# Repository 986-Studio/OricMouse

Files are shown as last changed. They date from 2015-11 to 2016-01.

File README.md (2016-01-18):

# OricMouse
OricMouse, an Expansion card to add Mouse to your Orices! (1, Atmos and Telestrat)

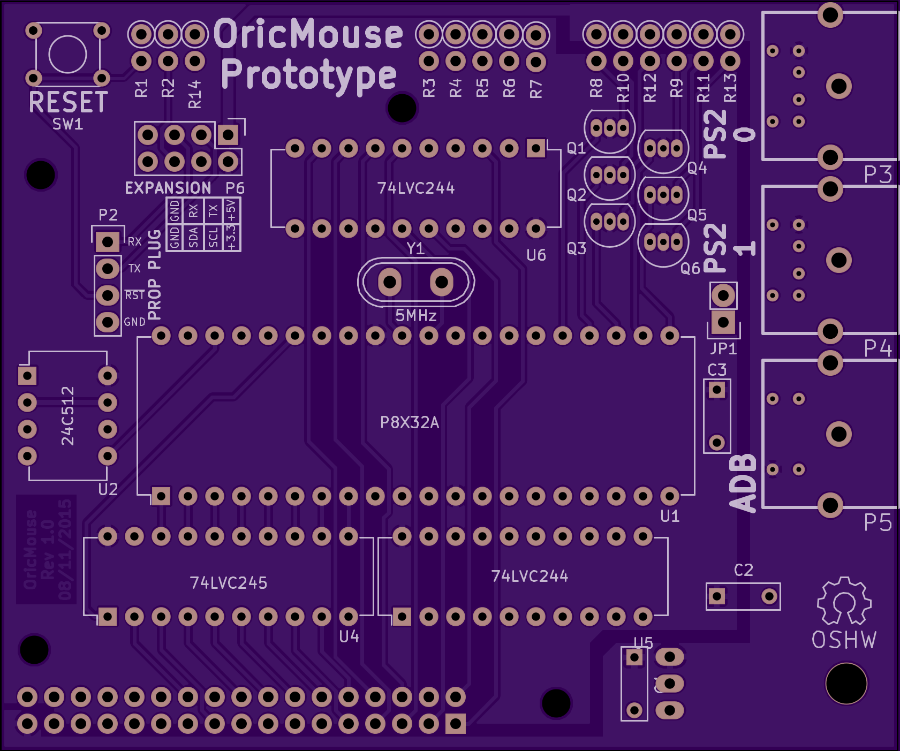
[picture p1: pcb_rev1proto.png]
PCB Design


You will find both the hardware and firmware of this project in this repository. 

OricMouse is an Open Source Hardware project.

Ready to order gerber can be found on OSHPark: https://oshpark.com/shared_projects/KOAZTB95

The correct license still need to be choosen, but please concidere it currently as something similar to the 4 clause BSD, share and use as wanted, but always tell from what your project is based, and who is the original author.
__Also if you make your own derived project, do not use the same name or a derived name.__ That mean that you can use the Oric name as I don't own this name, but don't use "OricMouse".

3D Rendering of the PCB:
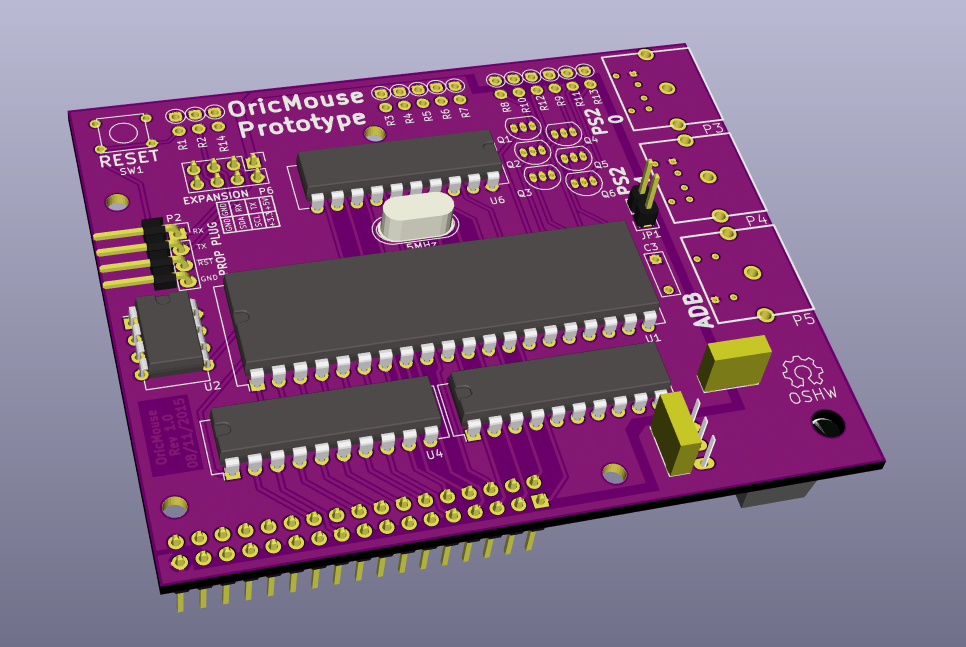
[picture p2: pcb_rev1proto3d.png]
3D Render of current PCB Design


Older revision of the PCB:
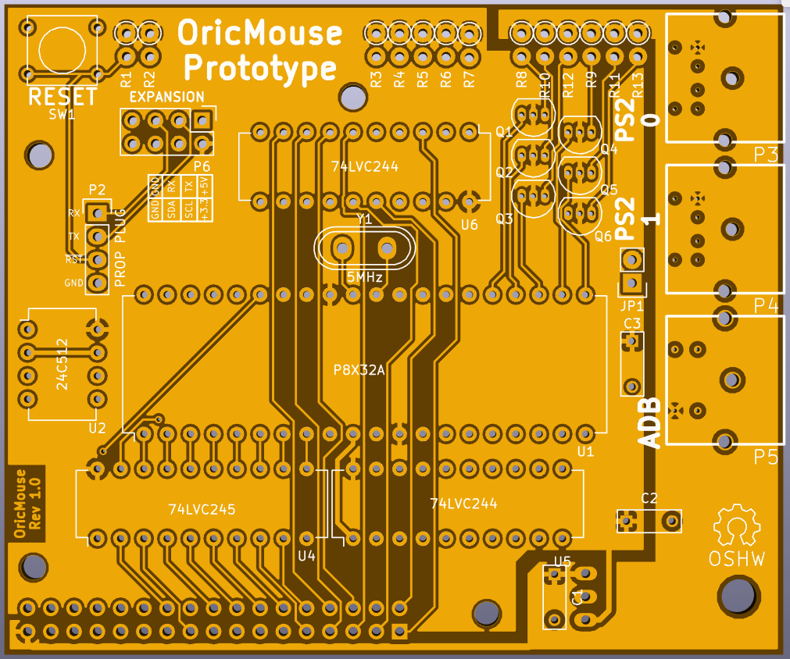
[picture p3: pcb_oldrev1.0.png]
Older PCB Design


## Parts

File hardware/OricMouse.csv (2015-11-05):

Id | Designator | Package | Quantity | Designation | Supplier and ref
1 | U3 | TO-220_Neutral123_Horizontal | 1 | LM2931AZ-3.3/5.0
2 | P5 | MiniDIN4 | 1 | ADB
3 | C1,C2 | C_Rect_L7_W2.5_P5 | 2 | 0.1uF
4 | C3 | C_Rect_L7_W2.5_P5 | 1 | 1uF
5 | JP1 | Pin_Header_Straight_1x02 | 1 | JUMPER
6 | P1 | Pin_Header_Straight_2x17 | 1 | CONN_02X17
7 | P6 | Pin_Header_Straight_2x04 | 1 | EXPANSION
8 | Q1,Q2,Q3,Q4,Q5,Q6 | TO-92_Inline_Narrow_Oval | 6 | BS170
9 | U1 | DIP-40_W15.24mm | 1 | P8X32A
10 | U2 | DIP-8_W7.62mm | 1 | 24C512
11 | U4 | DIP-20_W7.62mm | 1 | 74LVC245
12 | U5,U6 | DIP-20_W7.62mm | 2 | 74LVC244
13 | Y1 | Crystal_HC50-U_Vertical | 1 | 5MHz
14 | R13,R12,R11,R10,R9,R8,R7,R6,R5,R4,R3,R2,R1 | Resistor_Vertical_RM5mm | 13 | 10K
15 | P3 | MiniDIN6 | 1 | PS2/0
16 | P4 | MiniDIN6 | 1 | PS2 / 1
17 | SW1 | SW_PUSH_SMALL | 1 | RESET
18 | P2 | Pin_Header_Straight_1x04 | 1 | PROP PLUG
19 | REF** | Symbol_OSHW-Logo_SilkScreen | 1 | Symbol_OSHW-Logo_SilkScreen
20 | REF**,REF**,REF**,REF** | MountingHole_2-7mm | 4 | MountingHole_2-7mm

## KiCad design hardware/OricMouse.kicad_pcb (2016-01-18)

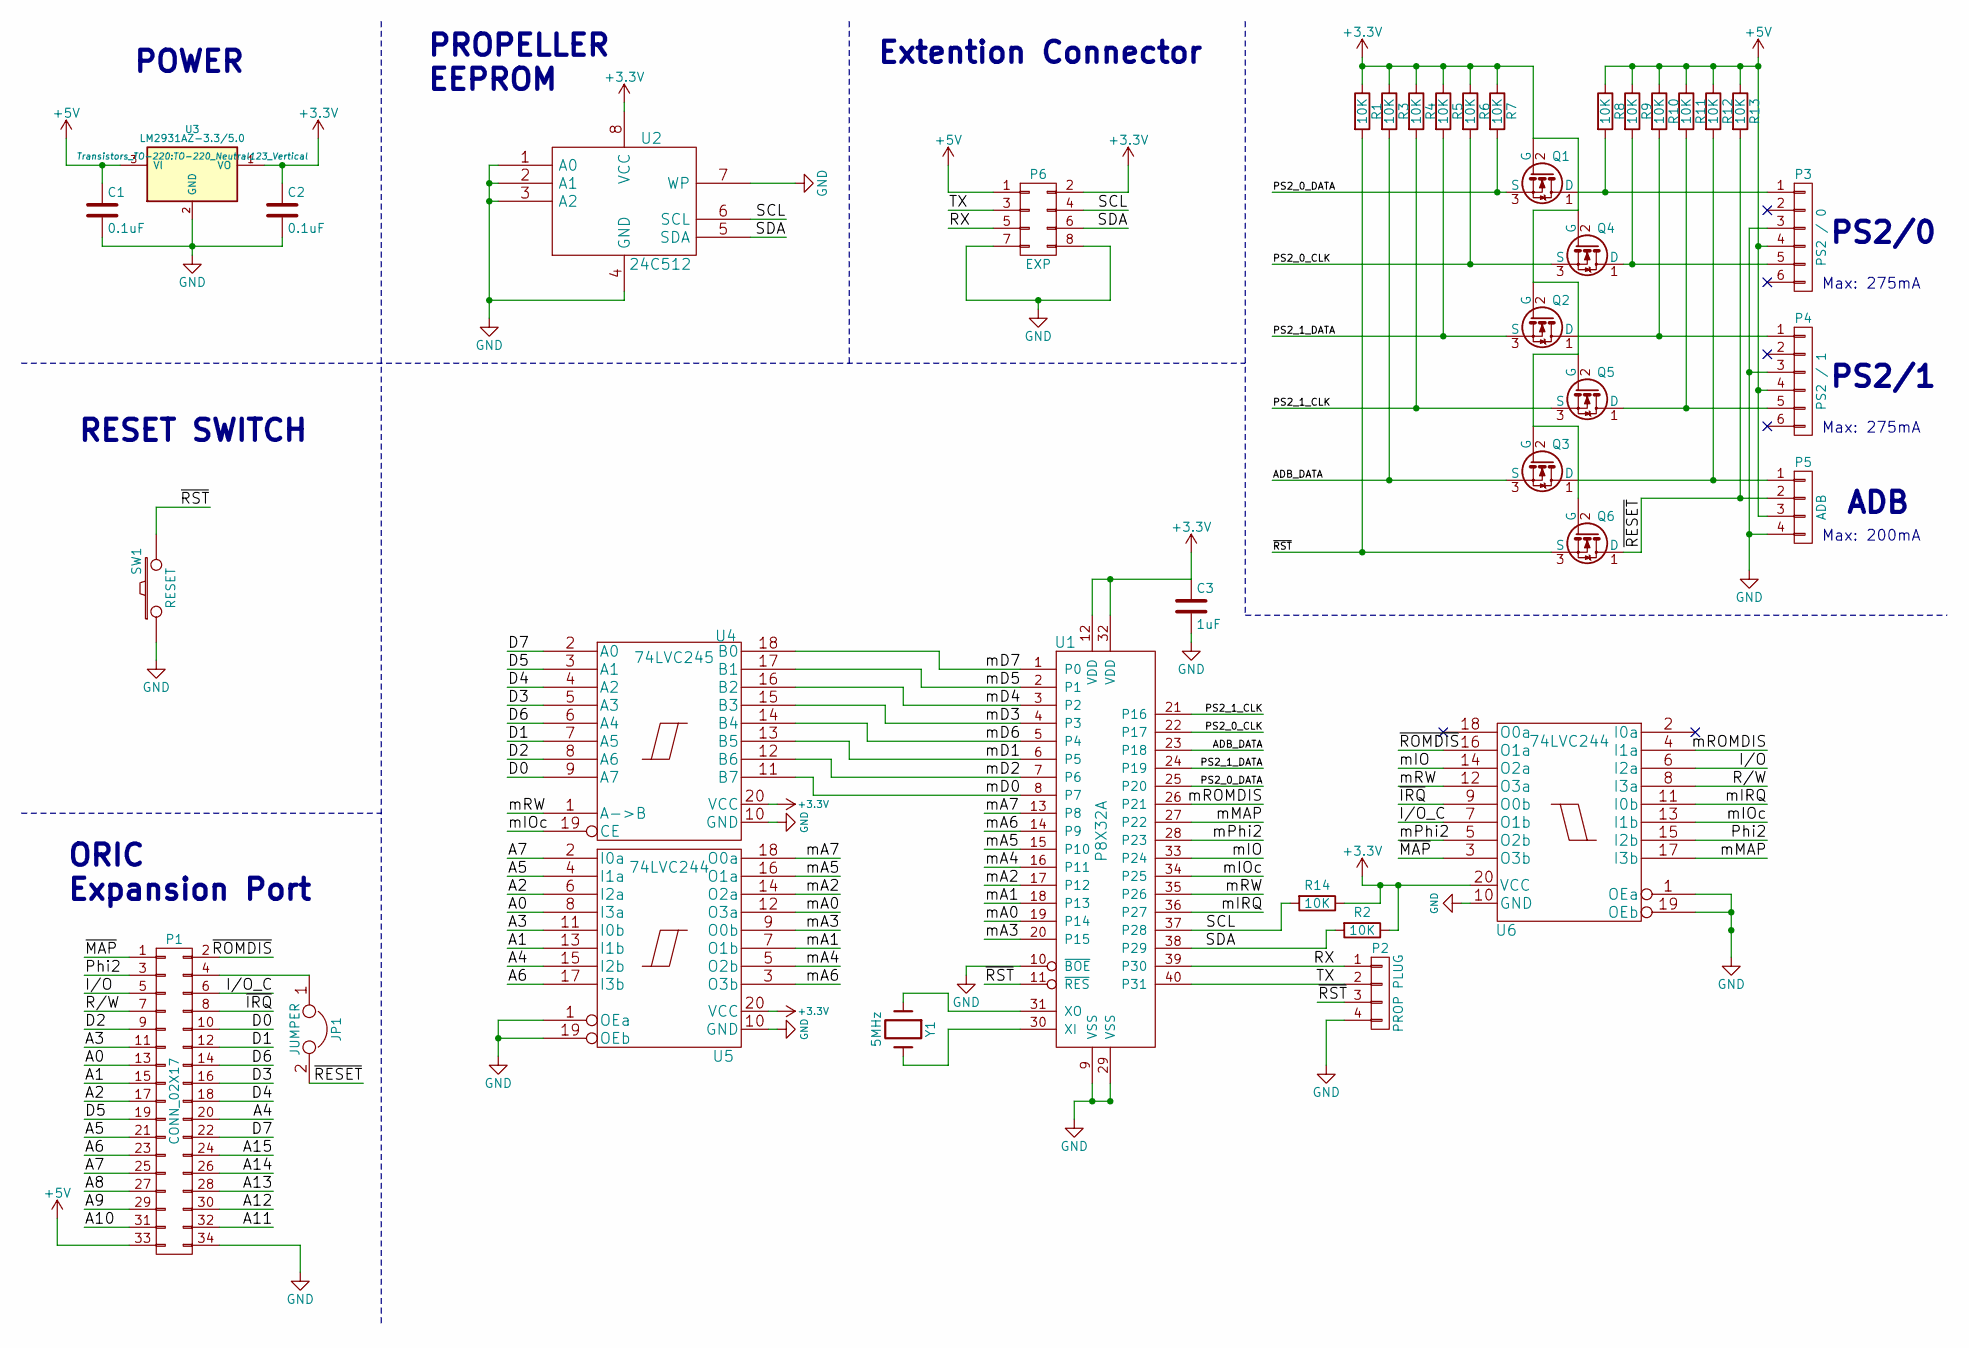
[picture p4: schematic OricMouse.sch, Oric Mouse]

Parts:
C1, C2: 0.1uF; C_Rect_L7_W2.5_P5
C3: 1uF; C_Rect_L7_W2.5_P5
JP1: JUMPER; Pin_Header_Straight_1x02
P1: CONN_02X17; Pin_Header_Straight_2x17
P2: PROP PLUG; Pin_Header_Straight_1x04
P3: PS2 / 0; MiniDIN6
P4: PS2 / 1; MiniDIN6
P5: ADB; MiniDIN4
P6: EXP; Pin_Header_Straight_2x04
Q1, Q2, Q3, Q4, Q5, Q6: BS170; TO-92_Inline_Narrow_Oval
R1, R2, R3, R4, R5, R6, R7, R8, R9, R10, R11, R12, R13, R14: 10K; Resistor_Vertical_RM5mm
SW1: RESET; SW_PUSH_SMALL
U1: P8X32A; DIP-40_W15.24mm
U2: 24C512; DIP-8_W7.62mm
U3: LM2931AZ-3.3/5.0; TO-220_Neutral123_Vertical
U4: 74LVC245; DIP-20_W7.62mm
U5, U6: 74LVC244; DIP-20_W7.62mm
Y1: 5MHz; Crystal_HC50-U_Vertical

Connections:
+5V: C1.1, P1.33, P3.4, P4.4, P5.3, P6.1, R8.1, R9.1, R10.1, R11.1, R12.1, R13.1, U3.3 (VI)
/A0: P1.13, U5.8 (I3a)
/A1: P1.15, U5.13 (I1b)
/A2: P1.17, U5.6 (I2a)
/A3: P1.11, U5.11 (I0b)
/A4: P1.20, U5.15 (I2b)
/A5: P1.21, U5.4 (I1a)
/A6: P1.23, U5.17 (I3b)
/A7: P1.25, U5.2 (I0a)
/A8: P1.27
/A9: P1.29
/A10: P1.31
/A11: P1.32
/A12: P1.30
/A13: P1.28
/A14: P1.26
/A15: P1.24
/ADB_DATA: Q3.3 (S), R3.2, U1.23 (P18)
/D0: P1.10, U4.9 (A7)
/D1: P1.12, U4.7 (A5)
/D2: P1.9, U4.8 (A6)
/D3: P1.16, U4.5 (A3)
/D4: P1.18, U4.4 (A2)
/D5: P1.19, U4.3 (A1)
/D6: P1.14, U4.6 (A4)
/D7: P1.22, U4.2 (A0)
/I/O: P1.5, U6.6 (I2a)
/I/O_C: P1.6, U6.7 (O1b)
/PS2_0_CLK: Q4.3 (S), R6.2, U1.22 (P17)
/PS2_0_DATA: Q1.3 (S), R7.2, U1.25 (P20)
/PS2_1_CLK: Q5.3 (S), R4.2, U1.21 (P16)
/PS2_1_DATA: Q2.3 (S), R5.2, U1.24 (P19)
/Phi2: P1.3, U6.15 (I2b)
/R/W: P1.7, U6.8 (I3a)
/RX: P2.1, P6.5, U1.39 (P30)
/SCL: P6.4, R14.2, U1.37 (P28), U2.6 (SCL)
/SDA: P6.6, R2.2, U1.38 (P29), U2.5 (SDA)
/TX: P2.2, P6.3, U1.40 (P31)
/mA0: U1.19 (P14), U5.12 (O3a)
/mA1: U1.18 (P13), U5.7 (O1b)
/mA2: U1.17 (P12), U5.14 (O2a)
/mA3: U1.20 (P15), U5.9 (O0b)
/mA4: U1.16 (P11), U5.5 (O2b)
/mA5: U1.15 (P10), U5.16 (O1a)
/mA6: U1.14 (P9), U5.3 (O3b)
/mA7: U1.13 (P8), U5.18 (O0a)
/mD0: U1.8 (P7), U4.11 (B7)
/mD1: U1.6 (P5), U4.13 (B5)
/mD2: U1.7 (P6), U4.12 (B6)
/mD3: U1.4 (P3), U4.15 (B3)
/mD4: U1.3 (P2), U4.16 (B2)
/mD5: U1.2 (P1), U4.17 (B1)
/mD6: U1.5 (P4), U4.14 (B4)
/mD7: U1.1 (P0), U4.18 (B0)
/mIO: U1.33 (P24), U6.14 (O2a)
/mIOc: U1.34 (P25), U4.19 (CE), U6.13 (I1b)
/mIRQ: U1.36 (P27), U6.11 (I0b)
/mMAP: U1.27 (P22), U6.17 (I3b)
/mPhi2: U1.28 (P23), U6.5 (O2b)
/mROMDIS: U1.26 (P21), U6.4 (I1a)
/mRW: U1.35 (P26), U4.1 (A->B), U6.12 (O3a)
/~IRQ: P1.8, U6.9 (O0b)
/~MAP: P1.1, U6.3 (O3b)
/~RESET: JP1.2, P5.2, Q6.1 (D), R13.2
/~ROMDIS: P1.2, U6.16 (O1a)
/~RST: P2.3, Q6.3 (S), R1.2, SW1.2, U1.11 (~RES)
unnamed: JP1.1, P1.4
unnamed: P3.1, Q1.1 (D), R8.2
unnamed: P3.5, Q4.1 (D), R9.2
unnamed: P4.1, Q2.1 (D), R10.2
unnamed: P4.5, Q5.1 (D), R11.2
unnamed: P5.1, Q3.1 (D), R12.2
unnamed: U1.30 (XI), Y1.2
unnamed: U1.31 (XO), Y1.1

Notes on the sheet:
Max: 200mA
Max: 275mA
ORIC Expansion Port
POWER
RESET SWITCH
PROPELLER EEPROM
PS2/0
PS2/1
ADB
Extention Connector

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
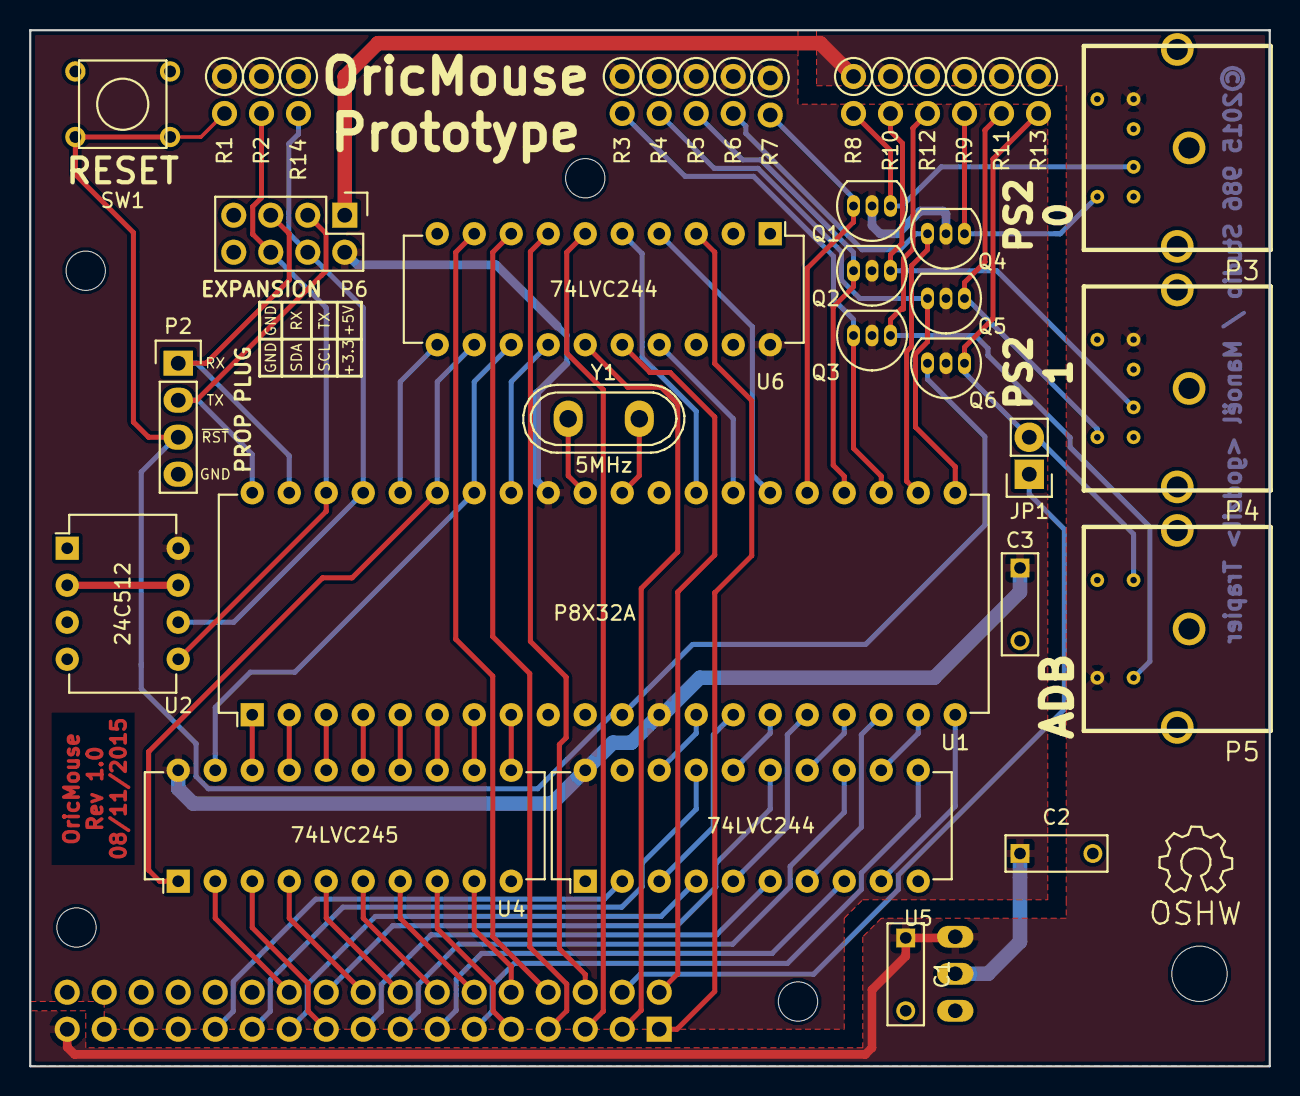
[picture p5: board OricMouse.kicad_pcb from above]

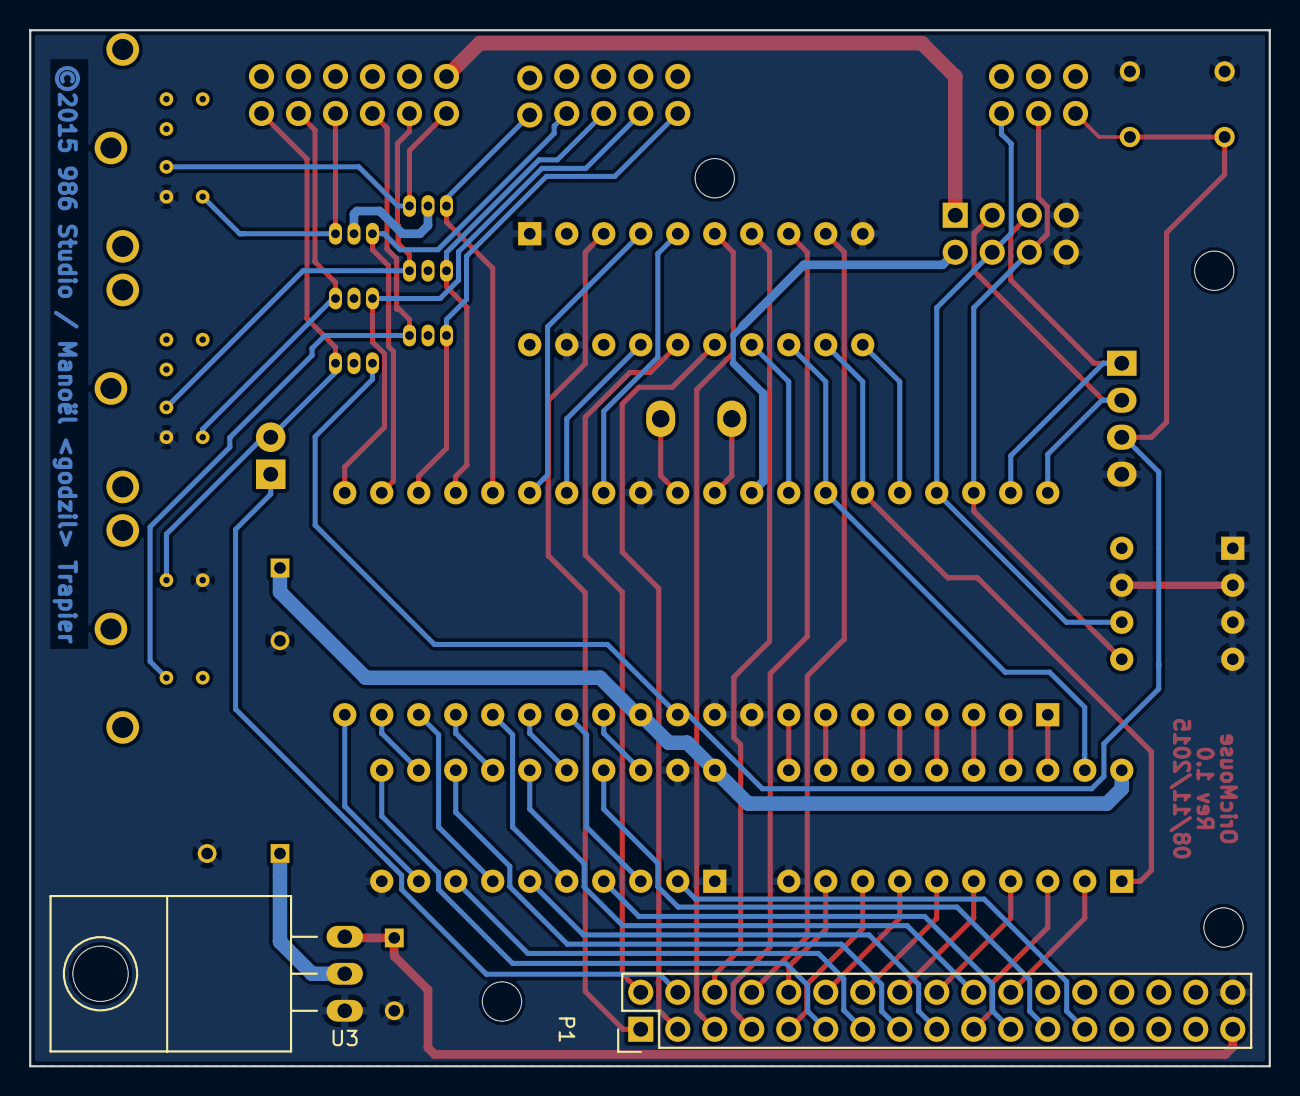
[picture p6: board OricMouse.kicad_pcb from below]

Board: 2 copper layers, 85.1 x 71.1 mm, 43 parts (2 on the bottom side), 68 nets.

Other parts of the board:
Hole1, Hole2, Hole3, Hole4: MountingHole_2-7mm
OSHW: Symbol_OSHW-Logo_SilkScreen

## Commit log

2015-11-05 Add Rev 1.0 of the OricMouse PCB
    [OricMouse.csv, OricMouse.kicad_pcb, OricMouse.sch]
2016-01-18 Add latest changes from 08/11/2015
    [OricMouse.kicad_pcb, OricMouse.sch]

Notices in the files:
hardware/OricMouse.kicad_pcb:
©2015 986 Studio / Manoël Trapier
